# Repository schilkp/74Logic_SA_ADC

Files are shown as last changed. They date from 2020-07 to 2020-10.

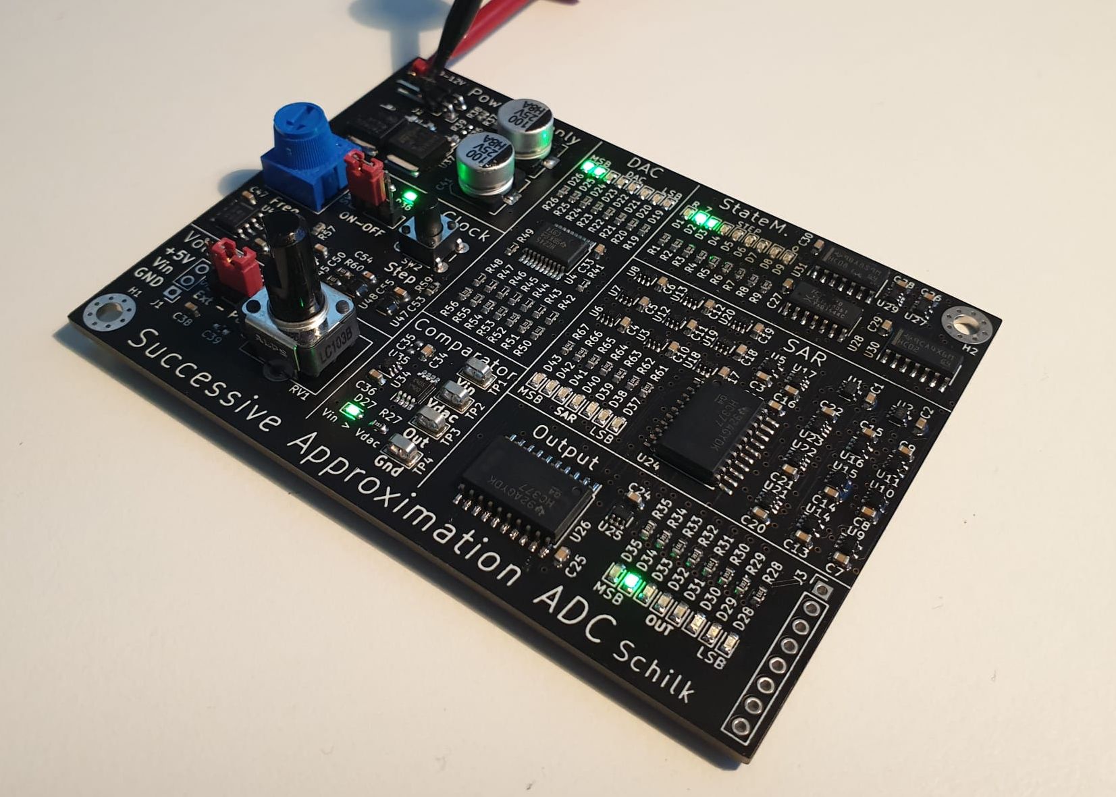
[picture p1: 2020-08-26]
Doc/SA-ADC_PCBphoto_v0.2.jpg

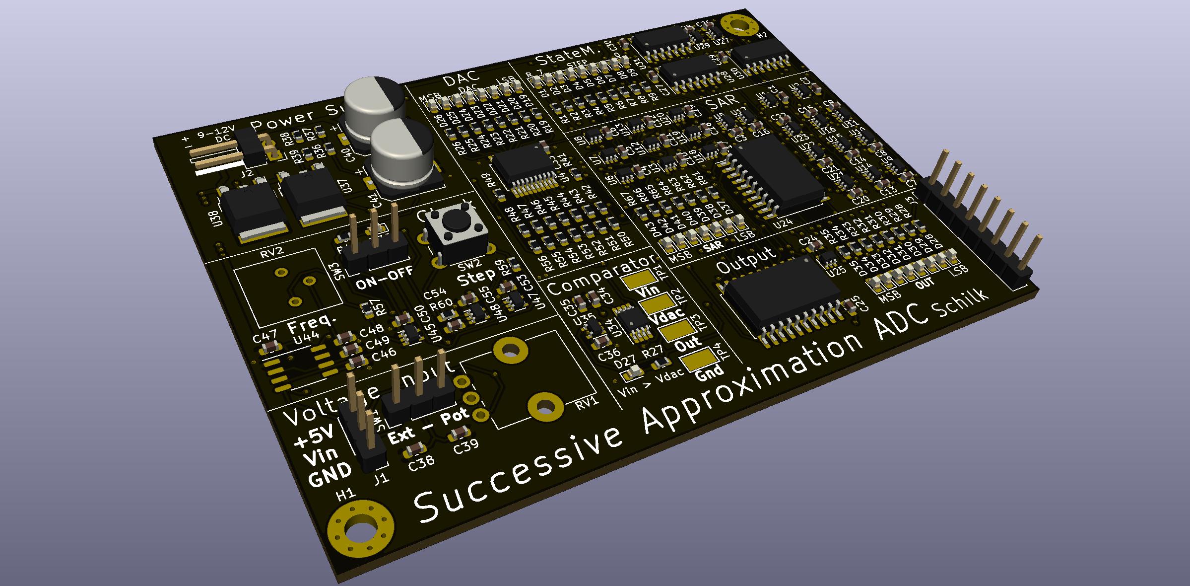
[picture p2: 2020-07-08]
Doc/SA-ADC_PCBrender_v0.2.jpg

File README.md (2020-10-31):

# SA-ADC
### Philipp Schilk
A discrete Successive-Approximation ADC built purely from 74-series gates.

Built to understand SA-ADCs, and serve as a demonstration unit.

PCB v0.2 Picture

PCB v0.2 Render

## Status
Finished. 

## Specifications
| Specification  | Value  |
| :--- | ---: |
| Resolution  | 8-bit  |
| Sample Rate  |  1Hz - 90Hz |
| Input Voltage Range | 0-5V |
| Input | Single-ended|
| Input Source | Included Potentiometer or External Input |
| Supply Voltage | 9-12Vdc |
| Output | 8-bit parallel |

As this is a demonstration unit only really meant for DC inputs, no Sample-&-Hold
stage is included.

## Successive Approximation Architecture

This Project uses the classic DAC-based Successive Approximation Architecture [Wikipedia](https://en.wikipedia.org/wiki/Successive_approximation_ADC "DAC-based Successive Approxmation Architecture").

It is essentially an analog implementation of a binary-search algorithm. The ADC first
it's DAC to 2.5V (Vref/2), and uses an analog comparator to determine if the applied input voltage is 
higher or lower than the generated voltage. Depending on the comparator's output the DAC voltage is 
then repeatedly refined to determine each bit of the conversion-result successively.

The steps of the conversion are show in the State-Machine outputs/LEDs:

|  LED  | Description |
| --- | --- |
| R | SAR (Successive Approximation Register) bits 6-1 are reset |
| 7 | Bit 7 is tested and latched if set. |
| 6 | Bit 6 is tested and latched if set. |
| ... | ... |
| 0 | Bit 0 is tested. Bit 7-1 are latched into the output from the SAR , and bit 0 is latched from the comparator |

*A note on clocks/timing:*
The state machine/shift-register is clocked on the falling edge, while the SAR (Successive Approximation Register) and the output register are 
latched on the rising edge. Due to this, all signals (including the DAC and hence the
comparator output) are setup on the falling edge of the clock by the state machine, and have until the 
rising edge of the clock to stabilize and be latched into the different registers. This reduces the complexity of the
state machine/logic somewhat.

## Repo Overview

**Doc/**  
	Documentation  

**KiCad/**  
	KiCad Project Files (Schematic and PCB).  
	Download KiCad at [kicad-pcb.org](https://kicad-pcb.org/download/).  

**KiCad/ProductionFiles/Gerber/**  
	Gerber production files.  

**KiCad/ProductionFiles/BOM/**  
	Interactive BOM  

**Logisim/**  
	Logic Simulation.  
	Download LogiSim at [cburch.com](http://www.cburch.com/logisim/).

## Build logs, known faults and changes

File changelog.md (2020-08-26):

# v0.3

- Changed to Schmitt-Trigger ICs  
- Added pull-down resistor to Clock Enable  

# v0.2

- Fixed State machine reset circuitry.
- Fixed Sate machine LEDs.
- Update chip names in schematic
- Fixed some vias in pads.

# v0.1

- Greatly simplified state machine & clocking:
	- State machine is now based on a shift register.
	- Now clocking state machine on falling clock and registers on rising edge.
		- Enables conversion in only 9 cycles.
- Moved to smaller, 2 layer PCB.
- Added mounting holes.
- Added ground test point. 
- Changed to 0603 LEDs
- Fixed missing ground on debouncing of step button.
- Slightly adjusted value of passives around clock.
	- 1M trimmer with knob is more easily available than 5M trimmer.

# v0.0

- Initial Prototype

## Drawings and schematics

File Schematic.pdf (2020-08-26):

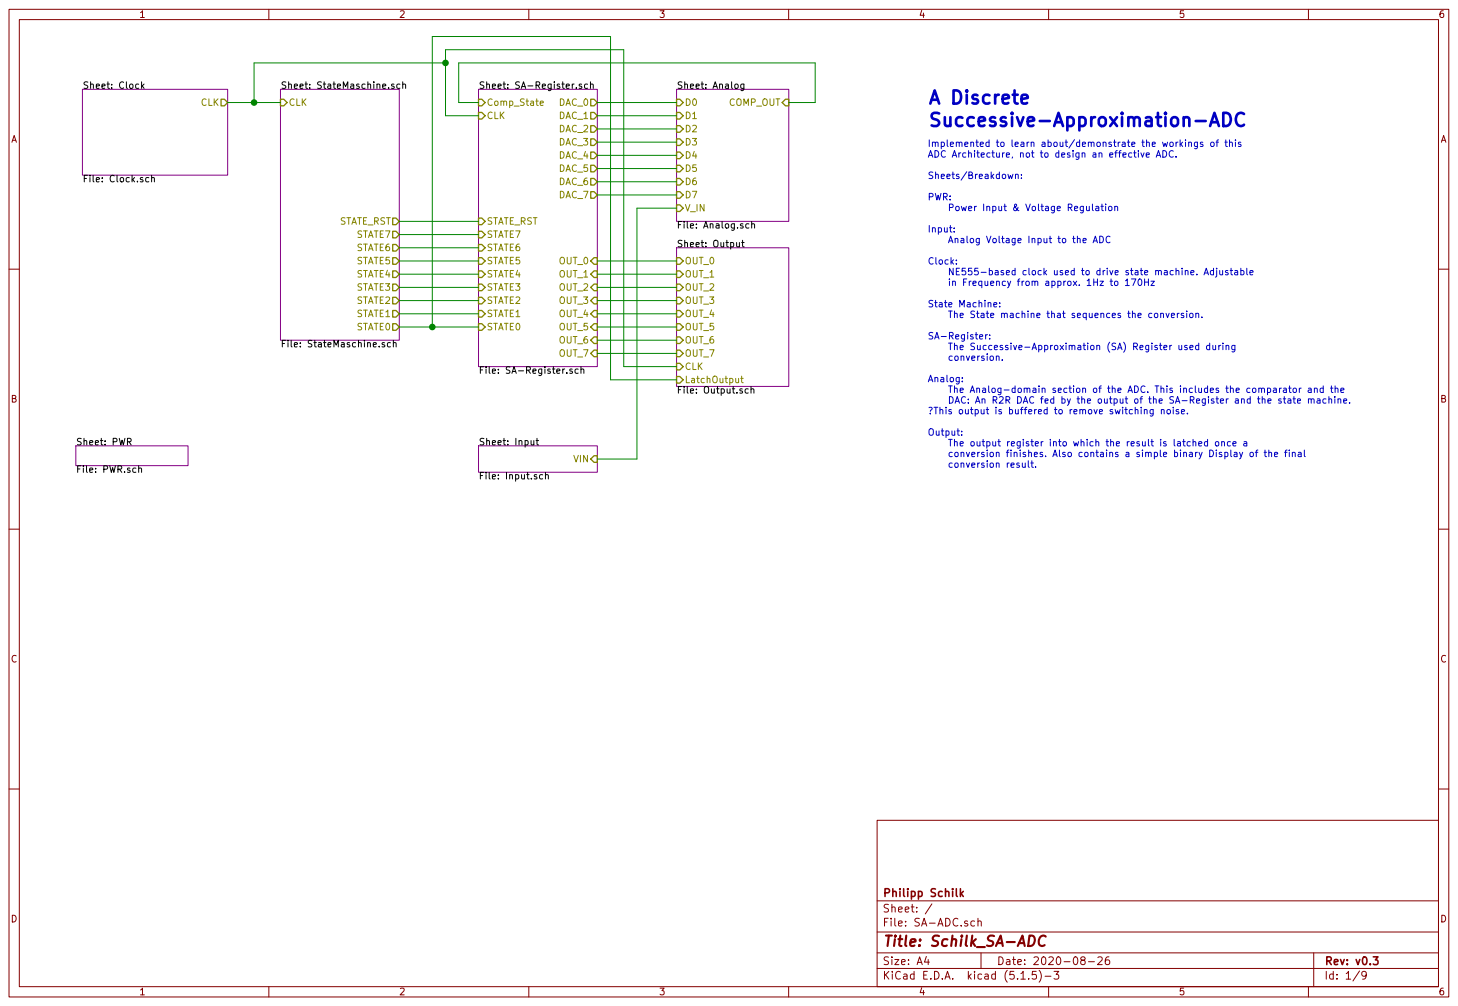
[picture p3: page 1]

COMP_OUT Sheet: StateMaschine.sch File: StateMaschine.sch CLK

Sheet: SA-Register.sch

Implemented to learn about/demonstrate the workings of this
ADC Architecture, not to design an effective ADC. Sheets/Breakdown: PWR:

Power Input & Voltage Regulation

Input:
Analog Voltage Input to the ADC

Clock:
NE555-based clock used to drive state machine. Adjustable
in Frequency from approx. 1Hz to 170Hz State Machine:

The State machine that sequences the conversion.

SA-Register:
The Successive-Approximation (SA) Register used during
conversion. Analog:

The Analog-domain section of the ADC. This includes the comparator and the
DAC: An R2R DAC fed by the output of the SA-Register and the state machine.
This output is buffered to remove switching noise.

Output:
The output register into which the result is latched once a
conversion finishes. Also contains a simple binary Display of the final

File: SA-ADC.sch Sheet: / Philipp Schilk

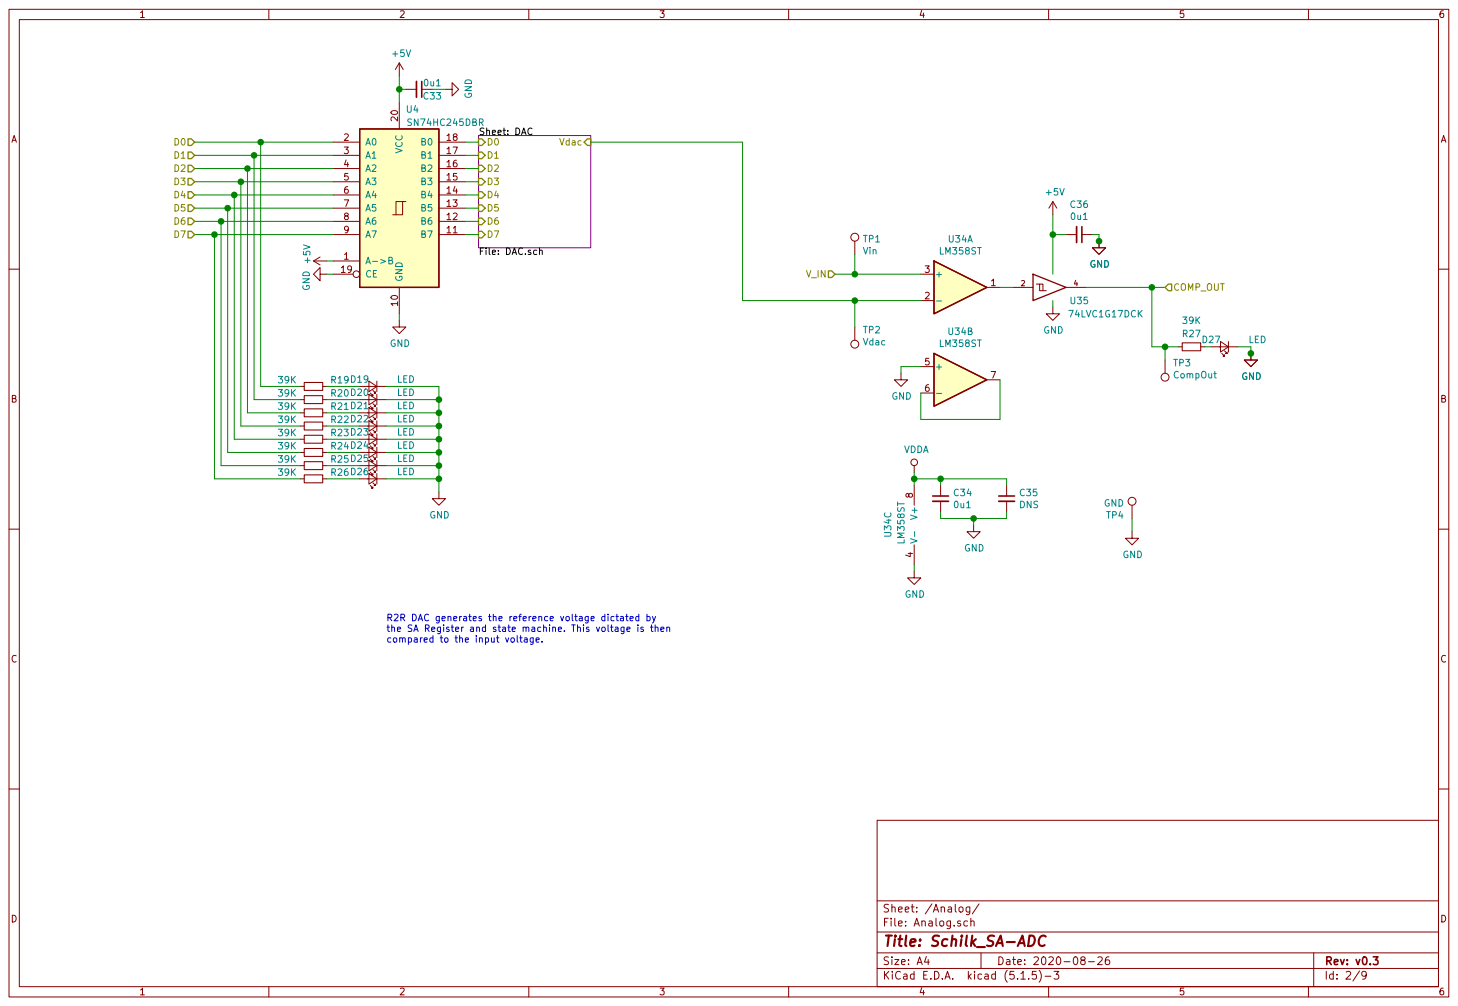
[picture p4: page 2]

the SA Register and state machine. This voltage is then
compared to the input voltage.

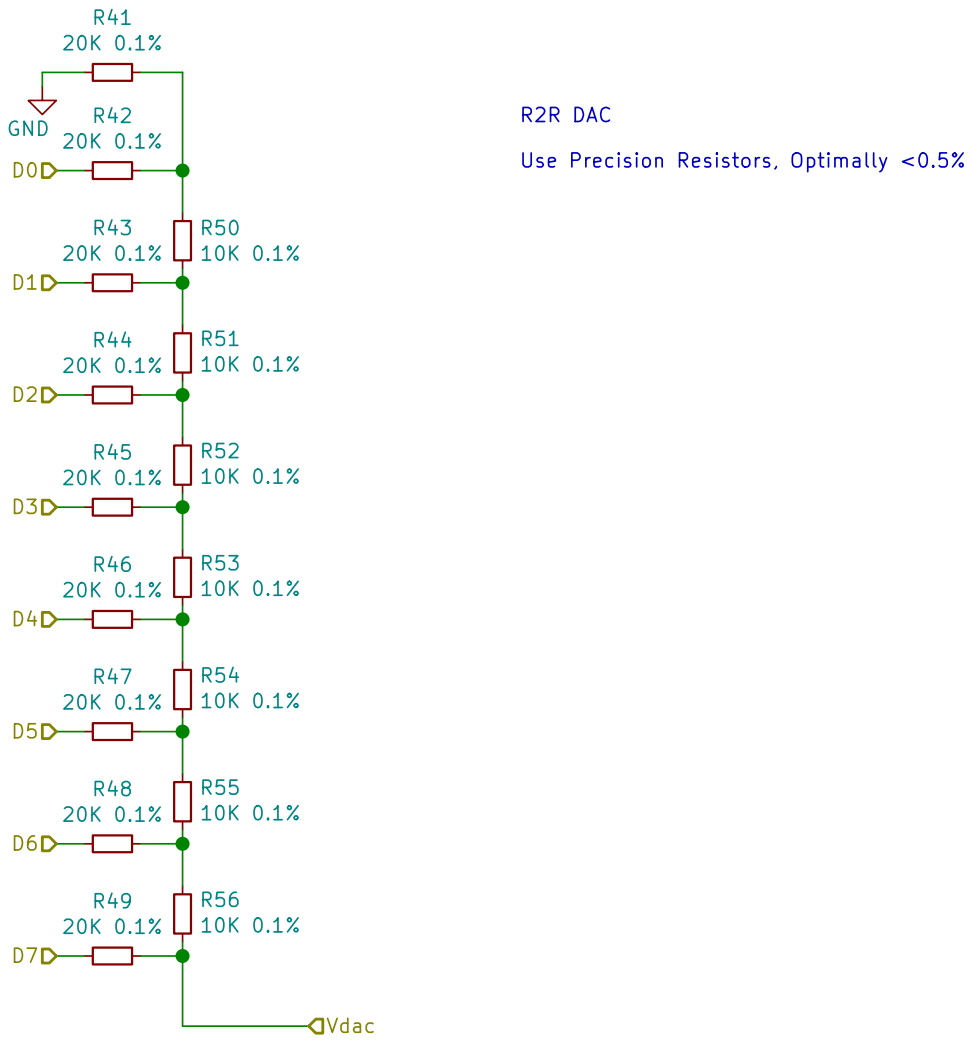
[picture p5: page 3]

Use Precision Resistors, Optimally <0.5%

File: DAC.sch Sheet: /Analog/DAC/ R56

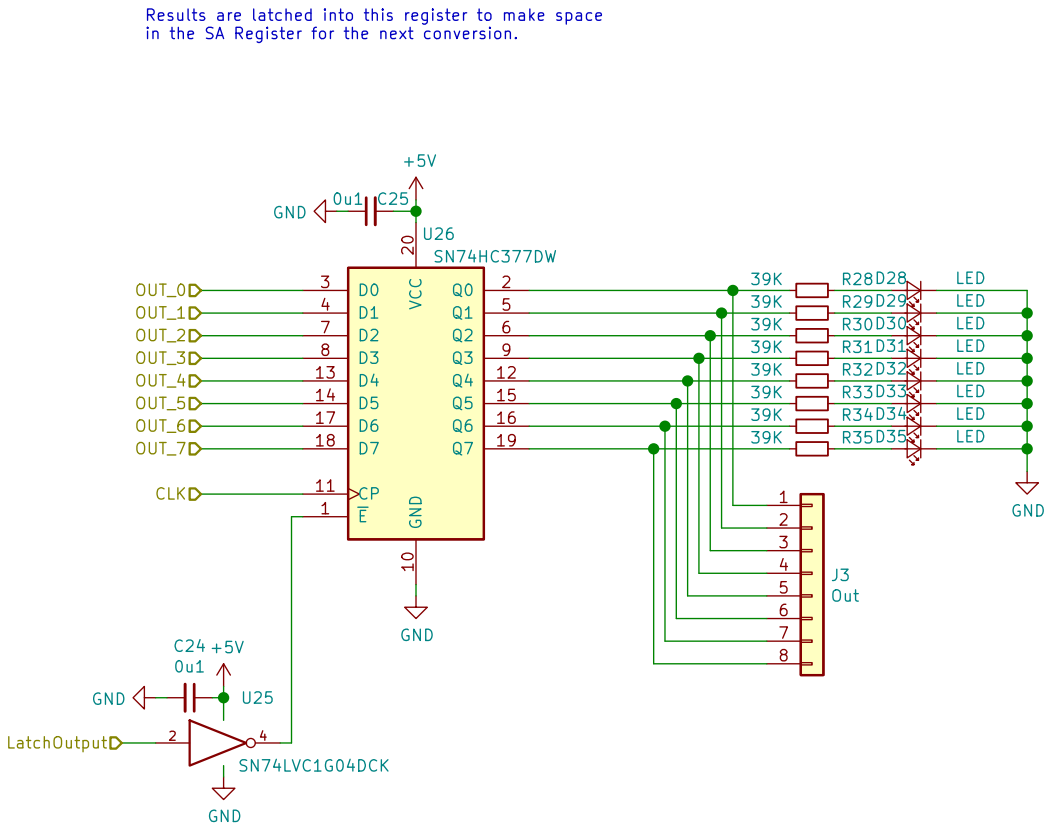
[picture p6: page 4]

in the SA Register for the next conversion.

39K R33 D33 | LED
D34 39K R34 | LED

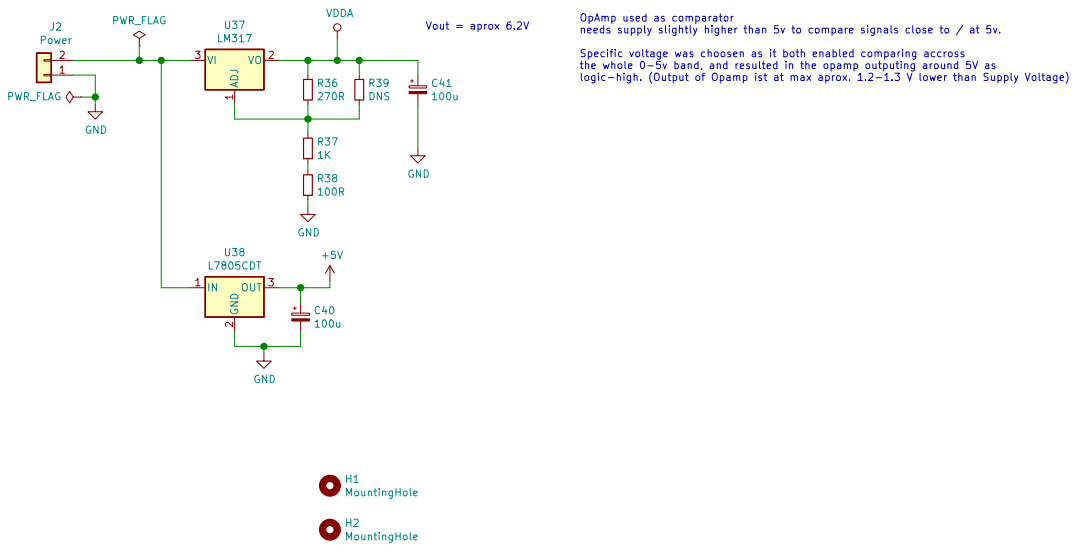
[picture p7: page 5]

needs supply slightly higher than 5v to compare signals close to / at 5v.

Specific voltage was choosen as it both enabled comparing accross
the whole 0-5v band, and resulted in the opamp outputing around 5V as
logic-high. (Output of Opamp ist at max aprox. 1.2-1.3 V lower than Supply Voltage)

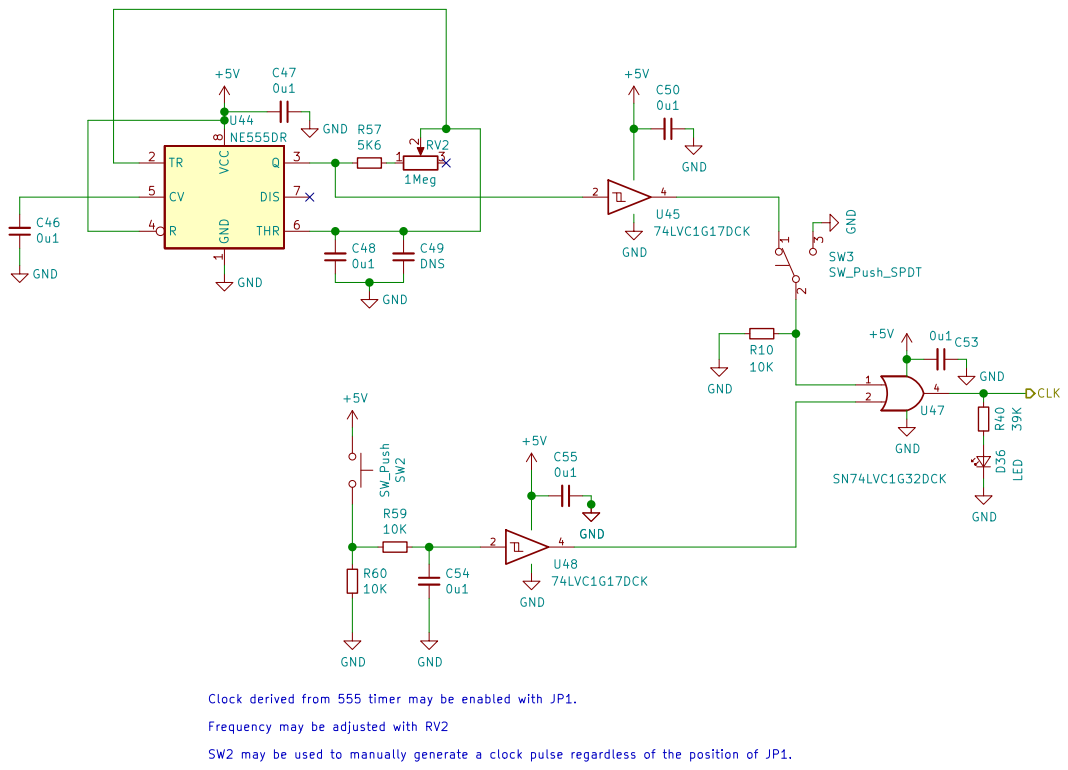
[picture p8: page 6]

File: Clock.sch Sheet: /Clock/ GND

CLK Clock derived from 555 timer may be enabled with JP1.

Frequency may be adjusted with RV2

SW2 may be used to manually generate a clock pulse regardless of the position of JP1.

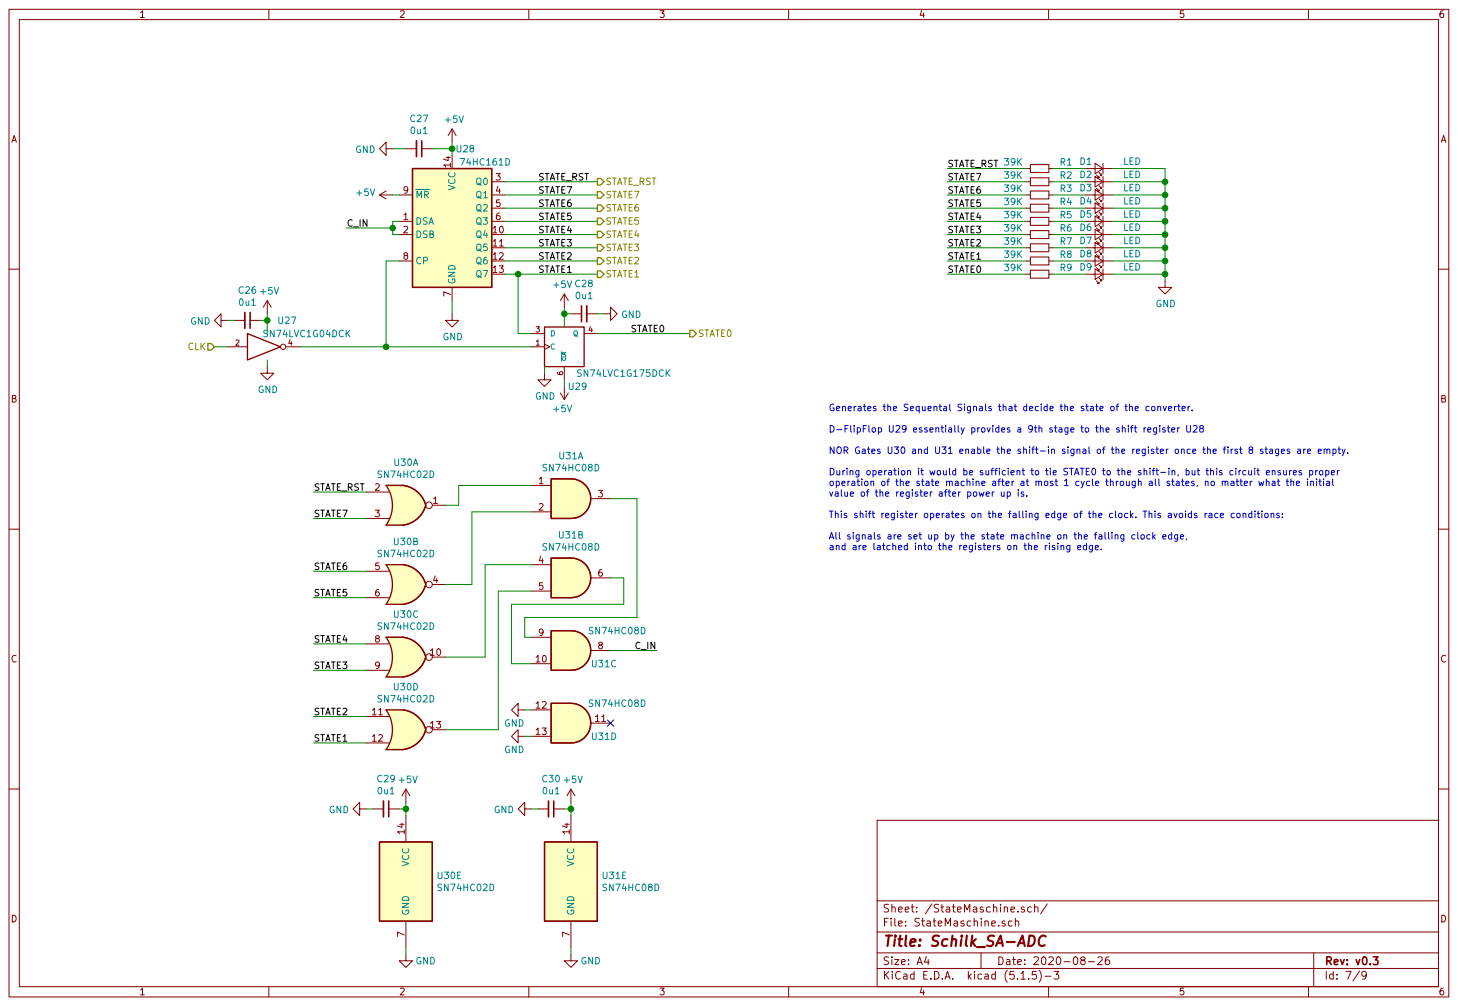
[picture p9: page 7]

D-FlipFlop U29 essentially provides a 9th stage to the shift register U28

NOR Gates U30 and U31 enable the shift-in signal of the register once the first 8 stages are empty.

During operation it would be sufficient to tie STATE0 to the shift-in, but this circuit ensures proper
operation of the state machine after at most 1 cycle through all states, no matter what the initial
value of the register after power up is.

This shift register operates on the falling edge of the clock. This avoids race conditions:

All signals are set up by the state machine on the falling clock edge,
and are latched into the registers on the rising edge.

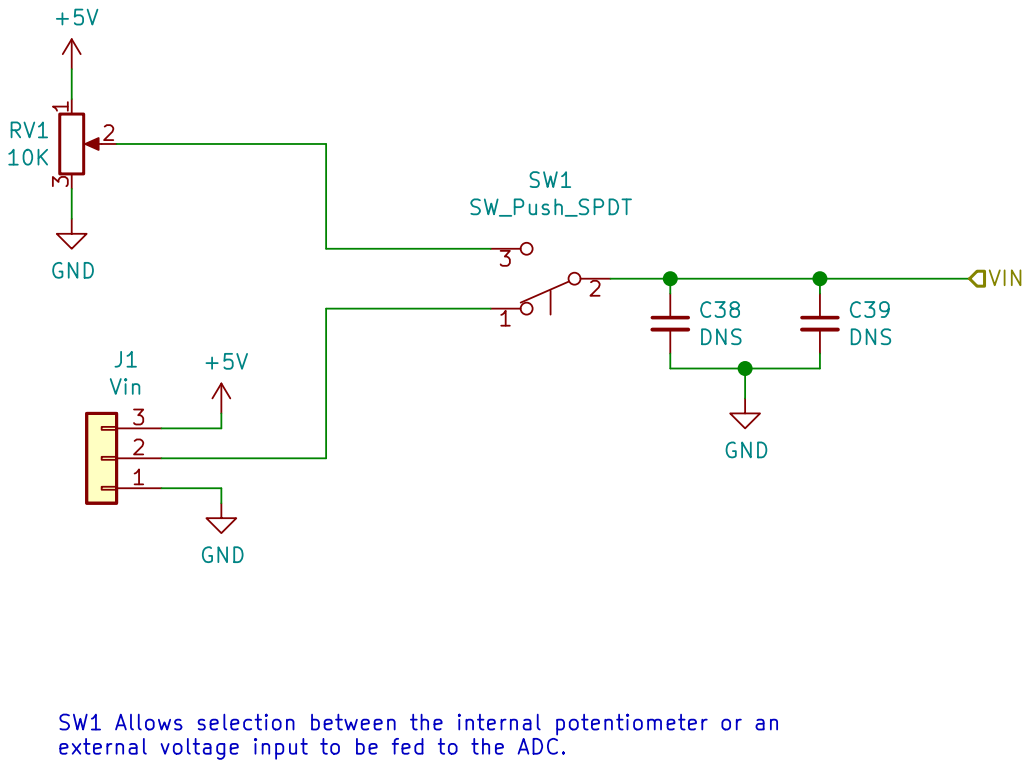
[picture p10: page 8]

SW1 Allows selection between the internal potentiometer or an
external voltage input to be fed to the ADC.

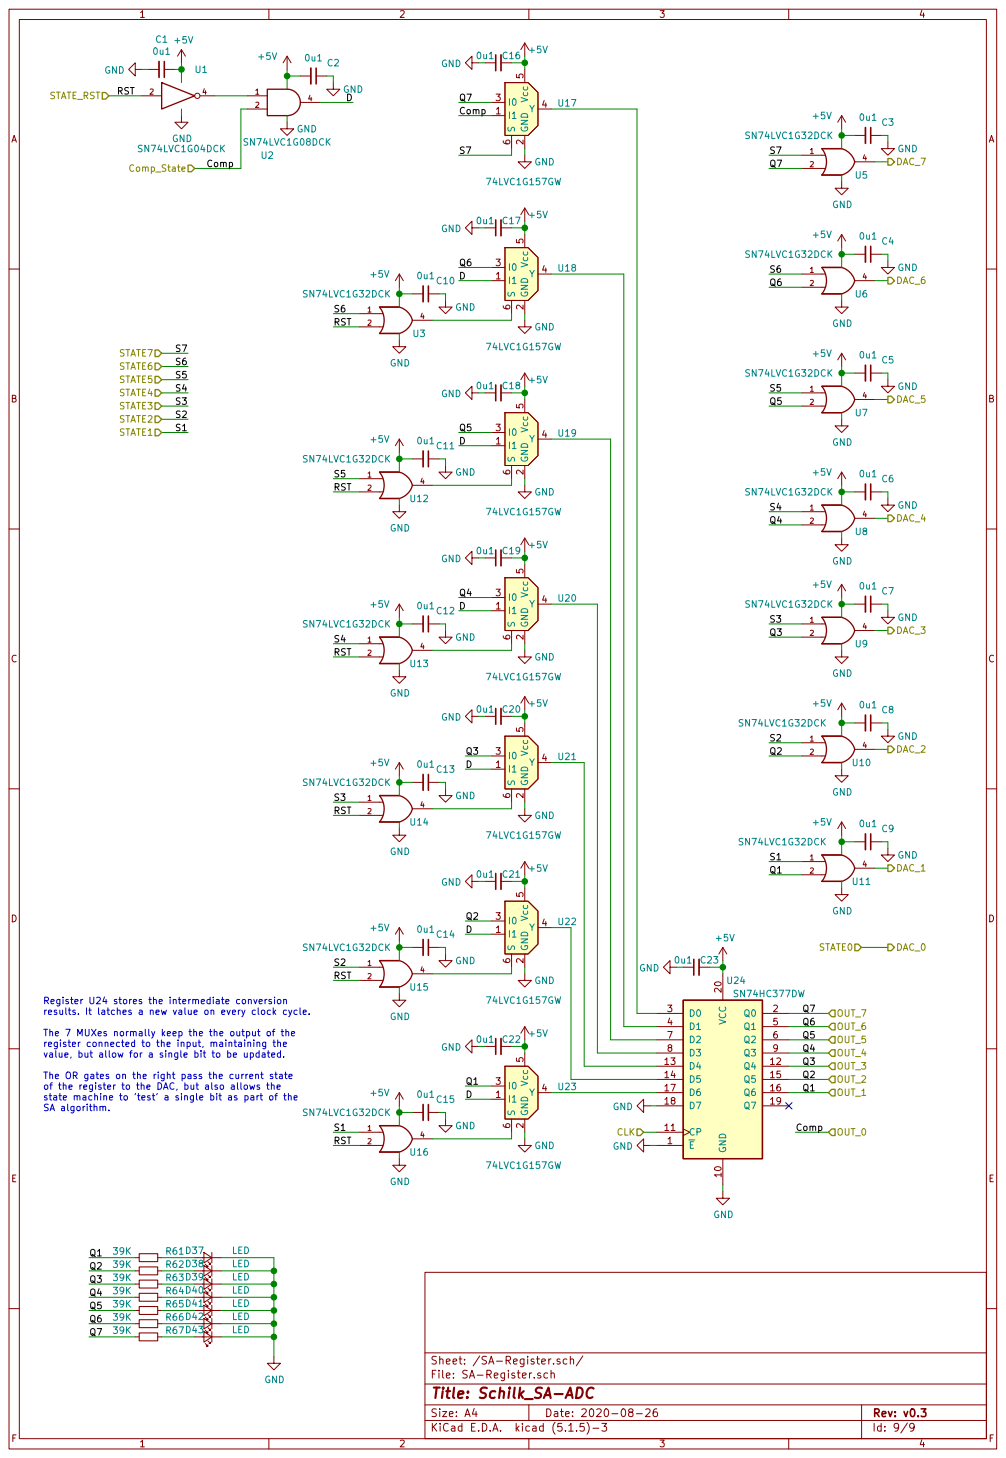
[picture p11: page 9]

results. It latches a new value on every clock cycle.

The 7 MUXes normally keep the the output of the
register connected to the input, maintaining the
value, but allow for a single bit to be updated.

The OR gates on the right pass the current state
of the register to the DAC, but also allows the
state machine to 'test' a single bit as part of the
SA algorithm.

File: SA-Register.sch
Id: 9/9 Title: Schilk_SA-ADC

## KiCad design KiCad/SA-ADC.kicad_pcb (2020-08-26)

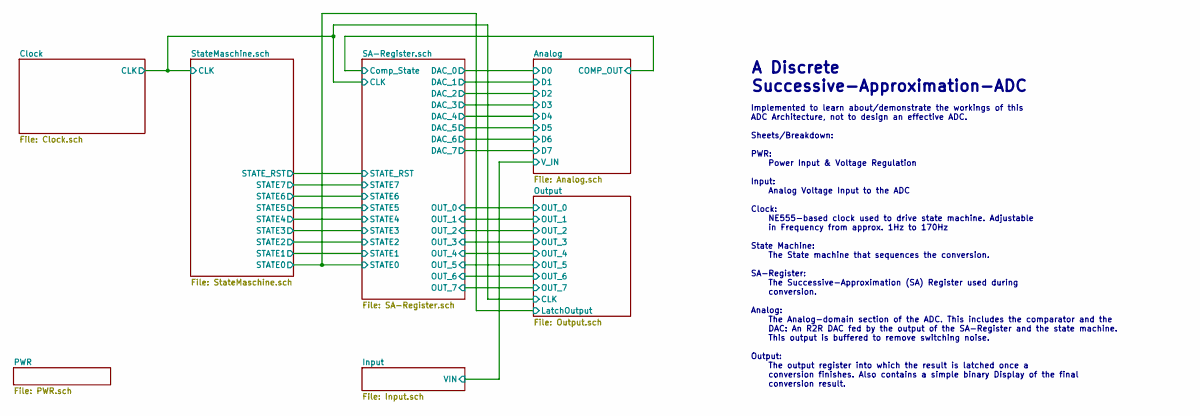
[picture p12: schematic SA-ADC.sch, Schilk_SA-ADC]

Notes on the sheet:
Implemented to learn about/demonstrate the workings of this ADC Architecture, not to design an effective ADC. Sheets/Breakdown: PWR: Power Input & Voltage Regulation Input: Analog Voltage Input to the ADC Clock: NE555-based clock used to drive state machine. Adjustable in Frequency from approx. 1Hz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
A Discrete Successive-Approximation-ADC

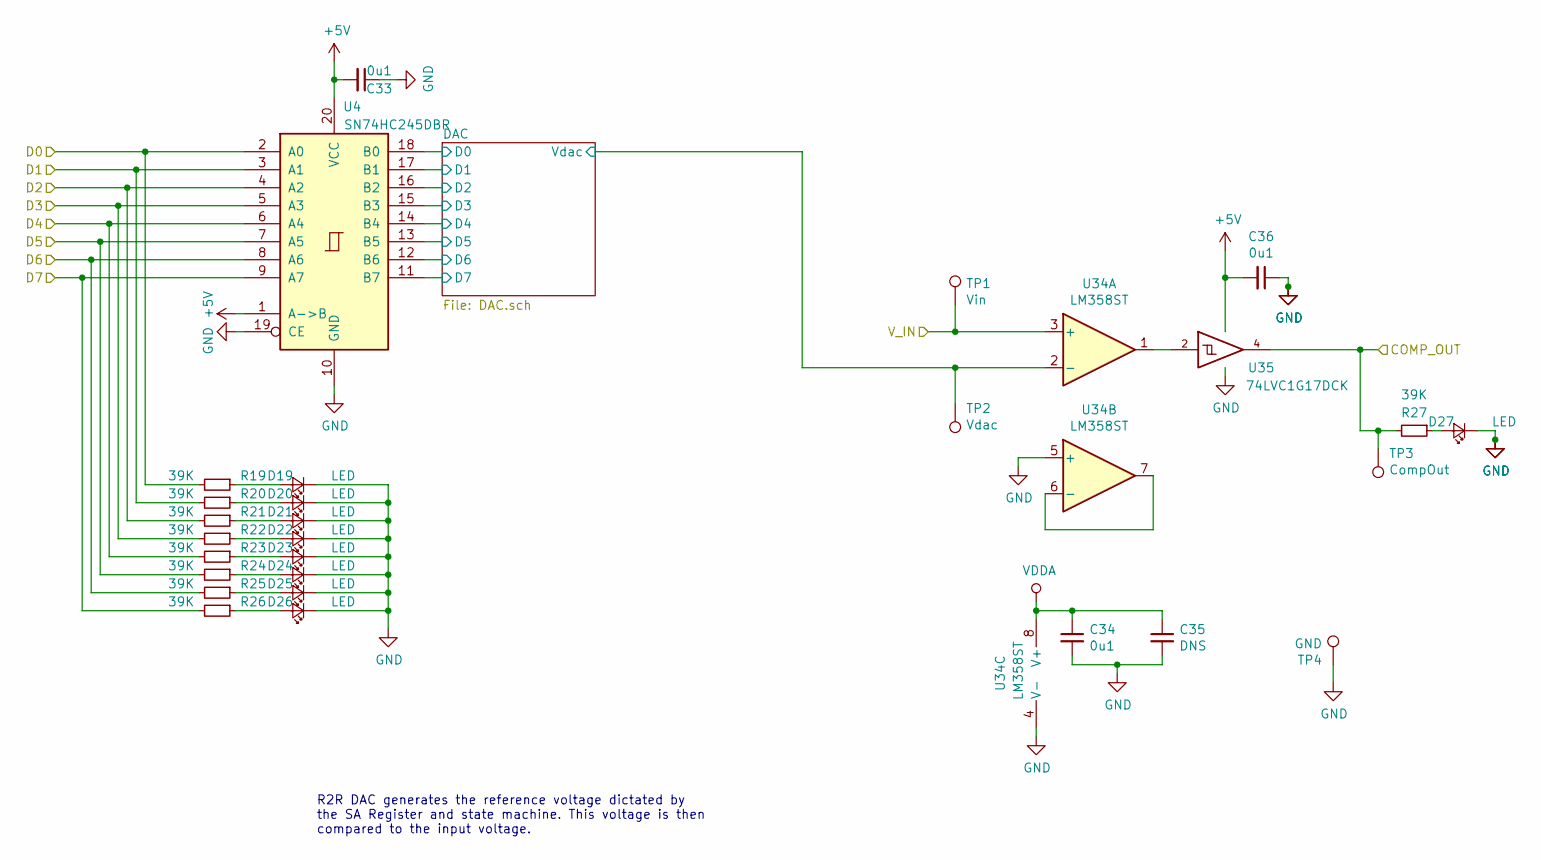
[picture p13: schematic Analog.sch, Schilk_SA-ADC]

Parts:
C33, C34, C36: 0u1; C_0603_1608Metric
C35: DNS; C_0603_1608Metric
D19, D20, D21, D22, D23, D24, D25, D26, D27: LED; LED_0603_1608Metric
R19, R20, R21, R22, R23, R24, R25, R26, R27: 39K; R_0603_1608Metric
TP1: Vin; TestPoint_Keystone_5019_Minature
TP2: Vdac; TestPoint_Keystone_5019_Minature
TP3: CompOut; TestPoint_Keystone_5019_Minature
TP4: GND; TestPoint_Keystone_5019_Minature
U4: SN74HC245DBR; SSOP-20_5.3x7.2mm_P0.65mm
U34: LM358ST; MSOP-8_3x3mm_P0.65mm
U35: 74LVC1G17DCK; SOT-353_SC-70-5

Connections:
+5V: C33.2, C36.2, U4.1 (A->B), U4.20 (VCC), U35.5 (VCC); also elsewhere on the board
/Analog/COMP_OUT: R27.2, TP3.1, U35.4; also elsewhere on the board
/Analog/D0: R19.2, U4.2 (A0); also elsewhere on the board
/Analog/D1: R20.2, U4.3 (A1); also elsewhere on the board
/Analog/D2: R21.2, U4.4 (A2); also elsewhere on the board
/Analog/D3: R22.2, U4.5 (A3); also elsewhere on the board
/Analog/D4: R23.2, U4.6 (A4); also elsewhere on the board
/Analog/D5: R24.2, U4.7 (A5); also elsewhere on the board
/Analog/D6: R25.2, U4.8 (A6); also elsewhere on the board
/Analog/D7: R26.2, U4.9 (A7); also elsewhere on the board
/Analog/DAC/D0: U4.18 (B0); also elsewhere on the board
/Analog/DAC/D1: U4.17 (B1); also elsewhere on the board
/Analog/DAC/D2: U4.16 (B2); also elsewhere on the board
/Analog/DAC/D3: U4.15 (B3); also elsewhere on the board
/Analog/DAC/D4: U4.14 (B4); also elsewhere on the board
/Analog/DAC/D5: U4.13 (B5); also elsewhere on the board
/Analog/DAC/D6: U4.12 (B6); also elsewhere on the board
/Analog/DAC/D7: U4.11 (B7); also elsewhere on the board
/Analog/DAC/Vdac: TP2.1, U34.2 (-); also elsewhere on the board
/Input/VIN: TP1.1, U34.3 (+); also elsewhere on the board
GND: C33.1, C34.2, C35.2, C36.1, D19.1 (K), D20.1 (K), D21.1 (K), D22.1 (K), D23.1 (K), D24.1 (K), D25.1 (K), D26.1 (K), D27.1 (K), TP4.1, U4.10 (GND), U4.19 (CE), U34.4 (V-), U34.5 (+), U35.3 (GND); also elsewhere on the board
unnamed: D19.2 (A), R19.1
unnamed: D20.2 (A), R20.1
unnamed: D21.2 (A), R21.1
unnamed: D22.2 (A), R22.1
unnamed: D23.2 (A), R23.1
unnamed: D24.2 (A), R24.1
unnamed: D25.2 (A), R25.1
unnamed: D26.2 (A), R26.1
unnamed: D27.2 (A), R27.1
unnamed: U34.1, U35.2
unnamed: U34.6 (-), U34.7
VDDA: C34.1, C35.1, U34.8 (V+); also elsewhere on the board

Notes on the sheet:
R2R DAC generates the reference voltage dictated by the SA Register and state machine. This voltage is then compared to the input voltage.

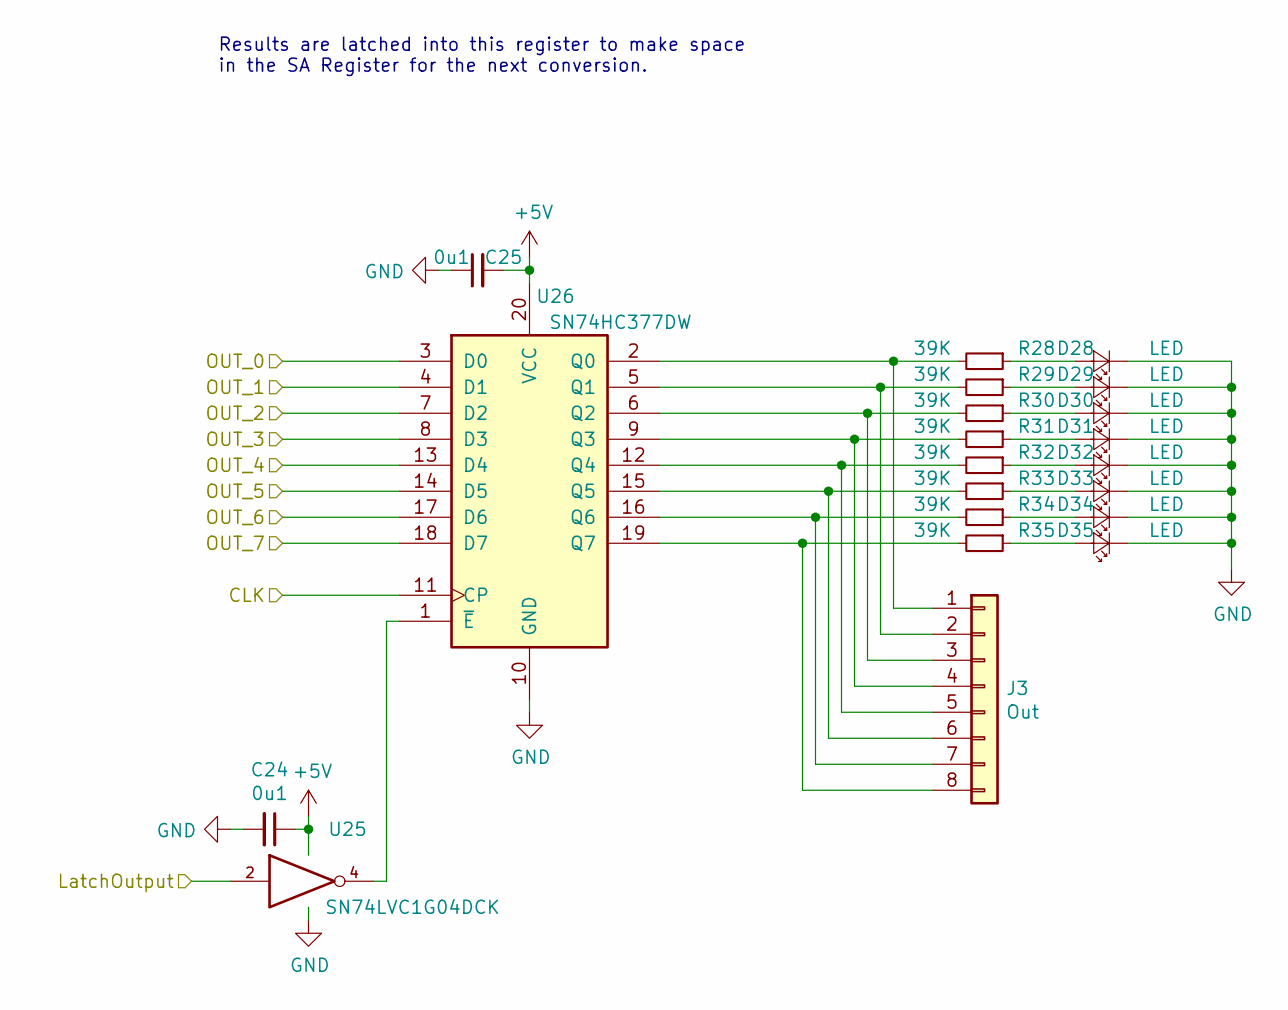
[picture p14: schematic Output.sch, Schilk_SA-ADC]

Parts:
C24, C25: 0u1; C_0603_1608Metric
D28, D29, D30, D31, D32, D33, D34, D35: LED; LED_0603_1608Metric
J3: Out; PinHeader_1x08_P2.54mm_Vertical
R28, R29, R30, R31, R32, R33, R34, R35: 39K; R_0603_1608Metric
U25: SN74LVC1G04DCK; SOT-353_SC-70-5
U26: SN74HC377DW; SOIC-20W_7.5x12.8mm_P1.27mm

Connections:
+5V: C24.1, C25.2, U25.5 (VCC), U26.20 (VCC); also elsewhere on the board
/Analog/COMP_OUT: U26.3 (D0); also elsewhere on the board
/Analog/D0: U25.2; also elsewhere on the board
/Clock/CLK: U26.11 (CP); also elsewhere on the board
/Output/OUT_1: U26.4 (D1); also elsewhere on the board
/Output/OUT_2: U26.7 (D2); also elsewhere on the board
/Output/OUT_3: U26.8 (D3); also elsewhere on the board
/Output/OUT_4: U26.13 (D4); also elsewhere on the board
/Output/OUT_5: U26.14 (D5); also elsewhere on the board
/Output/OUT_6: U26.17 (D6); also elsewhere on the board
/Output/OUT_7: U26.18 (D7); also elsewhere on the board
GND: C24.2, C25.1, D28.1 (K), D29.1 (K), D30.1 (K), D31.1 (K), D32.1 (K), D33.1 (K), D34.1 (K), D35.1 (K), U25.3 (GND), U26.10 (GND); also elsewhere on the board
unnamed: D28.2 (A), R28.1
unnamed: D29.2 (A), R29.1
unnamed: D30.2 (A), R30.1
unnamed: D31.2 (A), R31.1
unnamed: D32.2 (A), R32.1
unnamed: D33.2 (A), R33.1
unnamed: D34.2 (A), R34.1
unnamed: D35.2 (A), R35.1
unnamed: J3.1, R28.2, U26.2 (Q0)
unnamed: J3.2, R29.2, U26.5 (Q1)
unnamed: J3.3, R30.2, U26.6 (Q2)
unnamed: J3.4, R31.2, U26.9 (Q3)
unnamed: J3.5, R32.2, U26.12 (Q4)
unnamed: J3.6, R33.2, U26.15 (Q5)
unnamed: J3.7, R34.2, U26.16 (Q6)
unnamed: J3.8, R35.2, U26.19 (Q7)
unnamed: U25.4, U26.1 (~E)

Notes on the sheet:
Results are latched into this register to make space in the SA Register for the next conversion.

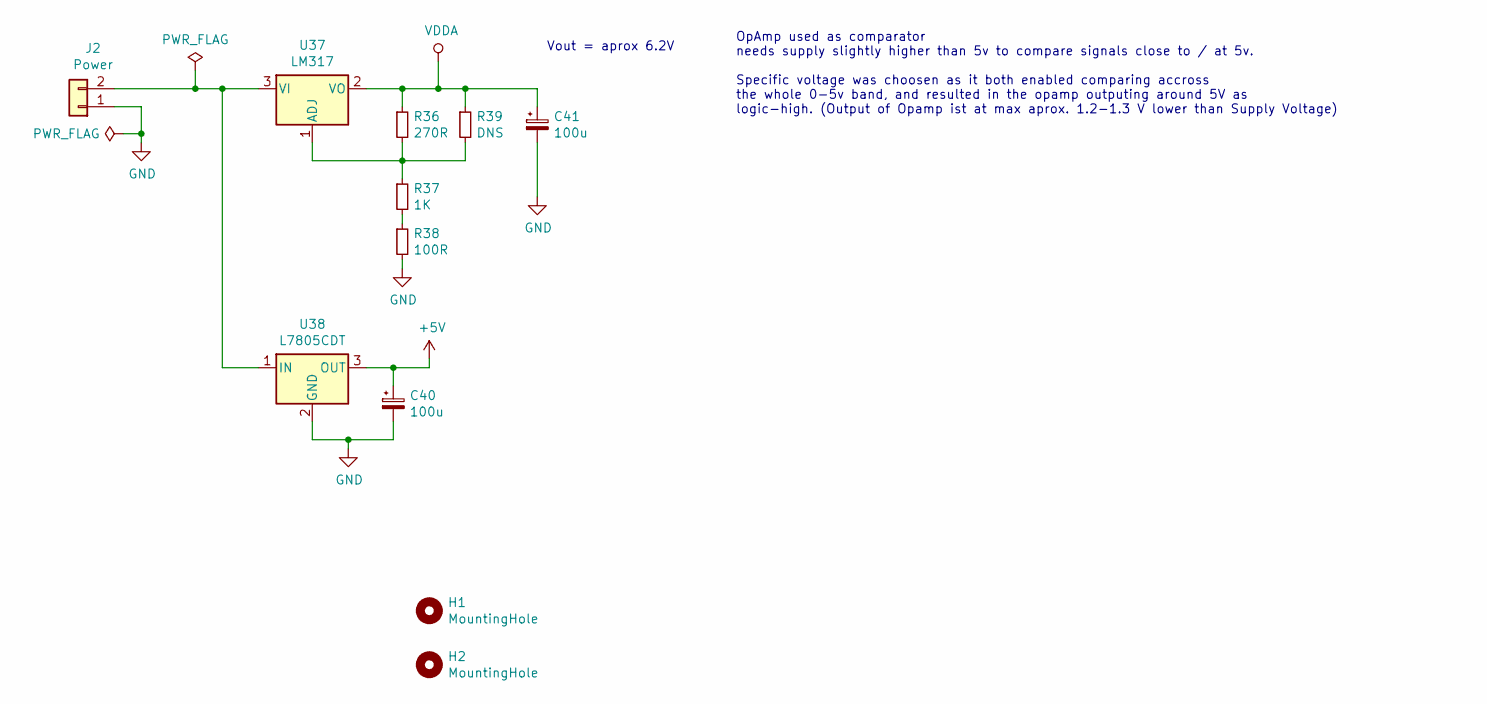
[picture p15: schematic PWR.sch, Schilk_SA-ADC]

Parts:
C40, C41: 100u; CP_Elec_8x6.5
H1, H2: MountingHole; MountingHole_3.2mm_M3_Pad_Via
J2: Power; PinHeader_1x02_P2.54mm_Horizontal
R36: 270R; R_0603_1608Metric
R37: 1K; R_0603_1608Metric
R38: 100R; R_0603_1608Metric
R39: DNS; R_0603_1608Metric
U37: LM317; TO-252-2
U38: L7805CDT; TO-252-2

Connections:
+5V: C40.1, U38.3 (OUT); also elsewhere on the board
GND: C40.2, C41.2, J2.1, R38.2, U38.2 (GND); also elsewhere on the board
unnamed: J2.2, U37.3 (VI), U38.1 (IN)
unnamed: R36.2, R37.1, R39.2, U37.1 (ADJ)
unnamed: R37.2, R38.1
VDDA: C41.1, R36.1, R39.1, U37.2 (VO); also elsewhere on the board

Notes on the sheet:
Vout = aprox 6.2V
OpAmp used as comparator needs supply slightly higher than 5v to compare signals close to / at 5v. Specific voltage was choosen as it both enabled comparing accross the whole 0-5v band, and resulted in the opamp outputing around 5V as logic-high. (Output of Opamp ist at max aprox. 1.2-1.3 V lower t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

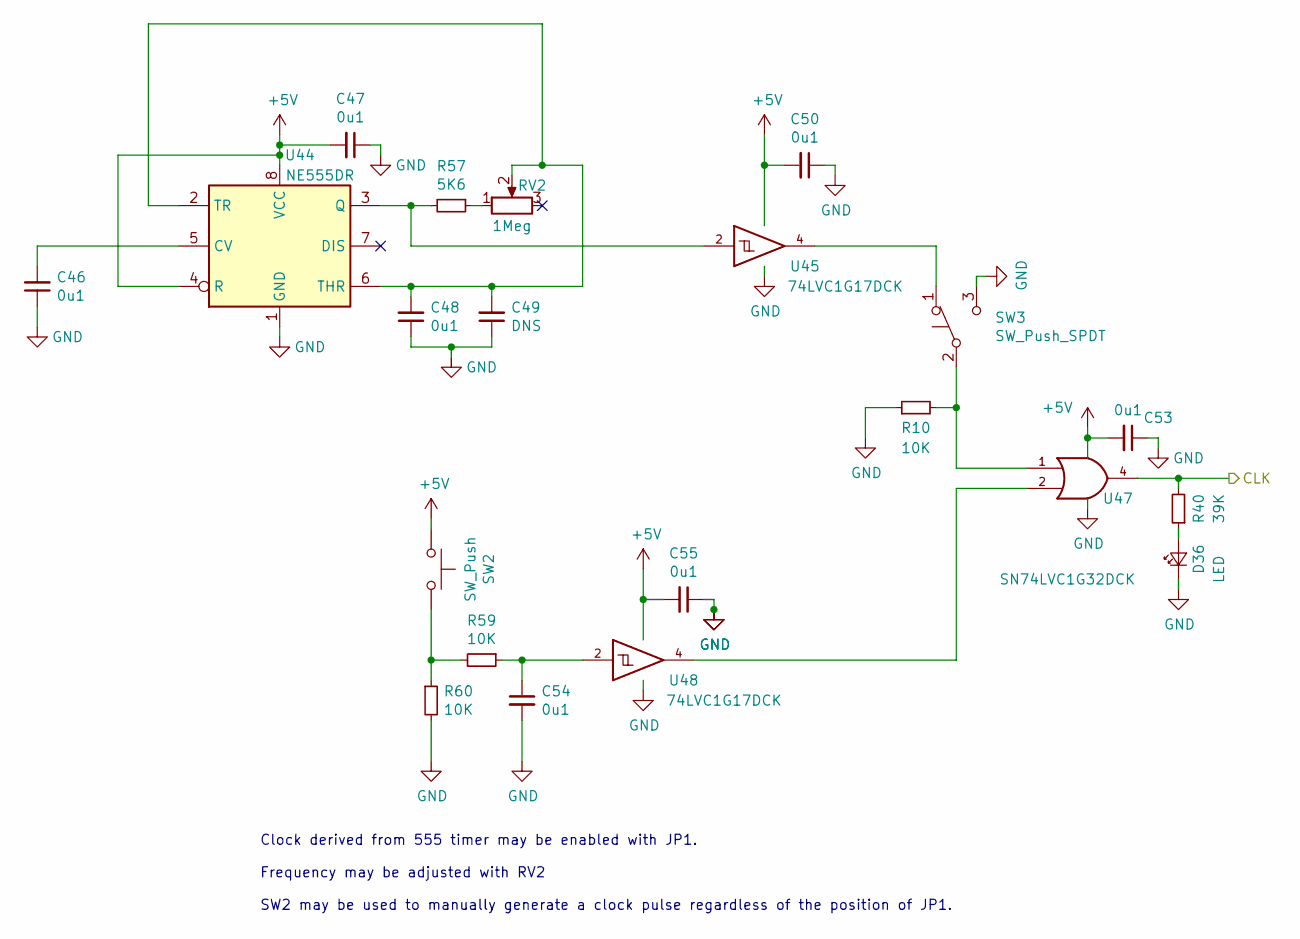
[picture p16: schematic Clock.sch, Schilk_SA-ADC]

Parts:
C46, C47, C48, C50, C53, C54, C55: 0u1; C_0603_1608Metric
C49: DNS; C_0603_1608Metric
D36: LED; LED_0603_1608Metric
R10, R59, R60: 10K; R_0603_1608Metric
R40: 39K; R_0603_1608Metric
R57: 5K6; R_0603_1608Metric
RV2: 1Meg; Potentiometer_Bourns_3386P_Vertical
SW2: SW_Push; SW_PUSH_6mm
SW3: SW_Push_SPDT; PinHeader_1x03_P2.54mm_Vertical
U44: NE555DR; SOP-8_3.9x4.9mm_P1.27mm
U45, U48: 74LVC1G17DCK; SOT-353_SC-70-5
U47: SN74LVC1G32DCK; SOT-353_SC-70-5

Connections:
+5V: C47.2, C50.2, C53.2, C55.2, SW2.1, U44.4 (R), U44.8 (VCC), U45.5 (VCC), U47.5 (VCC), U48.5 (VCC); also elsewhere on the board
/Clock/CLK: R40.2, U47.4; also elsewhere on the board
GND: C46.1, C47.1, C48.1, C49.1, C50.1, C53.1, C54.2, C55.1, D36.1 (K), R10.1, R60.2, SW3.3 (C), U44.1 (GND), U45.3 (GND), U47.3 (GND), U48.3 (GND); also elsewhere on the board
unnamed: C46.2, U44.5 (CV)
unnamed: C48.2, C49.2, RV2.2, U44.2 (TR), U44.6 (THR)
unnamed: C54.1, R59.1, U48.2
unnamed: D36.2 (A), R40.1
unnamed: R10.2, SW3.2 (B), U47.1
unnamed: R57.1, RV2.1
unnamed: R57.2, U44.3 (Q), U45.2
unnamed: R59.2, R60.1, SW2.2
unnamed: SW3.1 (A), U45.4
unnamed: U47.2, U48.4

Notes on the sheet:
Clock derived from 555 timer may be enabled with JP1. Frequency may be adjusted with RV2 SW2 may be used to manually generate a clock pulse regardless of the position of JP1.

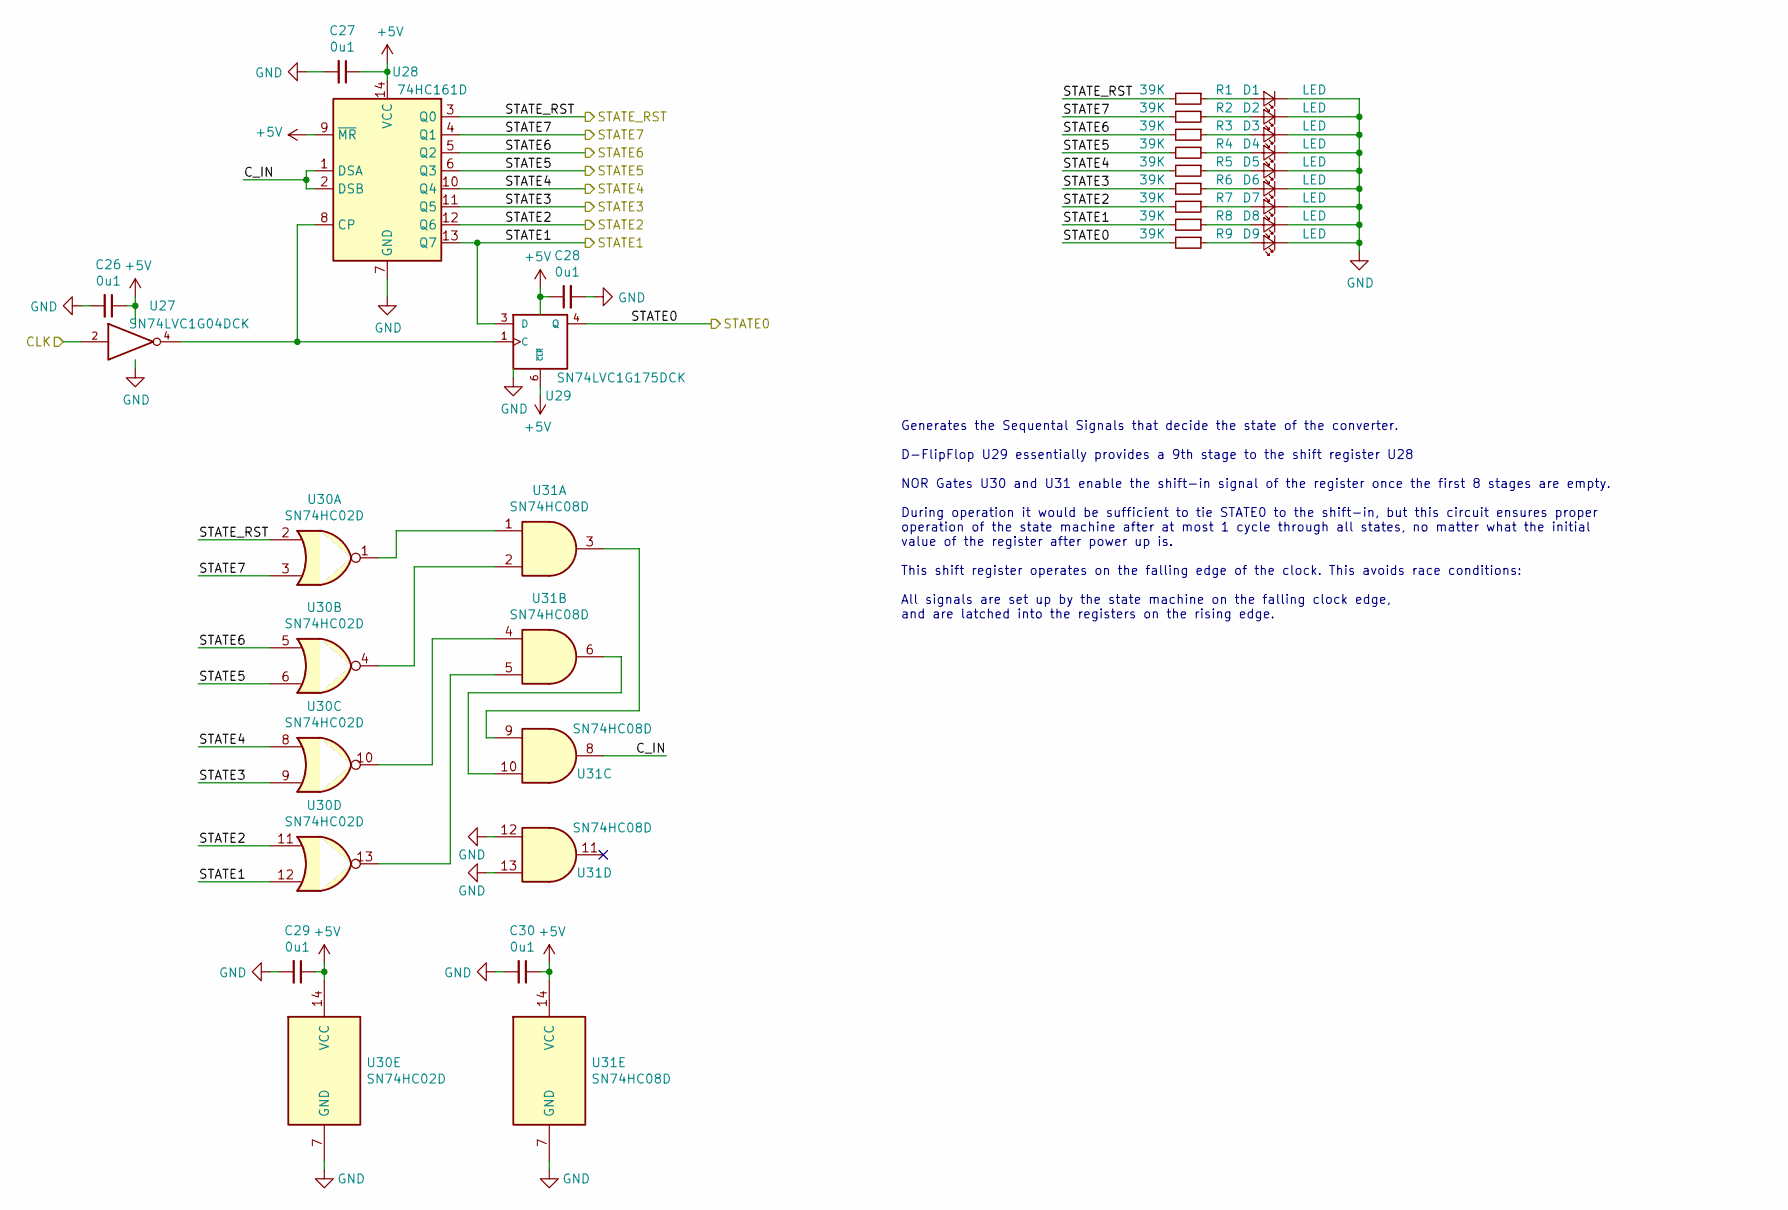
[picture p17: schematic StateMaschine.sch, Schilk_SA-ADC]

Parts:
C26, C27, C28, C29, C30: 0u1; C_0603_1608Metric
D1, D2, D3, D4, D5, D6, D7, D8, D9: LED; LED_0603_1608Metric
R1, R2, R3, R4, R5, R6, R7, R8, R9: 39K; R_0603_1608Metric
U27: SN74LVC1G04DCK; SOT-353_SC-70-5
U28: 74HC161D; SOIC-14_3.9x8.7mm_P1.27mm
U29: SN74LVC1G175DCK; SOT-363_SC-70-6
U30: SN74HC02D; SOIC-14_3.9x8.7mm_P1.27mm
U31: SN74HC08D; SOIC-14_3.9x8.7mm_P1.27mm

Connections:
+5V: C26.1, C27.1, C28.1, C29.1, C30.1, U27.5 (VCC), U28.9 (~MR), U28.14 (VCC), U29.5 (VCC), U29.6 (~CLR), U30.14 (VCC), U31.14 (VCC); also elsewhere on the board
/Analog/D0: R9.2, U29.4 (Q); also elsewhere on the board
/Clock/CLK: U27.2; also elsewhere on the board
/SA-Register.sch/STATE1: R8.2, U28.13 (Q7), U29.3 (D), U30.12; also elsewhere on the board
/SA-Register.sch/STATE2: R7.2, U28.12 (Q6), U30.11; also elsewhere on the board
/SA-Register.sch/STATE3: R6.2, U28.11 (Q5), U30.9; also elsewhere on the board
/SA-Register.sch/STATE4: R5.2, U28.10 (Q4), U30.8; also elsewhere on the board
/SA-Register.sch/STATE5: R4.2, U28.6 (Q3), U30.6; also elsewhere on the board
/SA-Register.sch/STATE6: R3.2, U28.5 (Q2), U30.5; also elsewhere on the board
/SA-Register.sch/STATE7: R2.2, U28.4 (Q1), U30.3; also elsewhere on the board
/SA-Register.sch/STATE_RST: R1.2, U28.3 (Q0), U30.2; also elsewhere on the board
/StateMaschine.sch/C_IN: U28.1 (DSA), U28.2 (DSB), U31.8
GND: C26.2, C27.2, C28.2, C29.2, C30.2, D1.1 (K), D2.1 (K), D3.1 (K), D4.1 (K), D5.1 (K), D6.1 (K), D7.1 (K), D8.1 (K), D9.1 (K), U27.3 (GND), U28.7 (GND), U29.2 (GND), U30.7 (GND), U31.7 (GND), U31.12, U31.13; also elsewhere on the board
unnamed: D1.2 (A), R1.1
unnamed: D2.2 (A), R2.1
unnamed: D3.2 (A), R3.1
unnamed: D4.2 (A), R4.1
unnamed: D5.2 (A), R5.1
unnamed: D6.2 (A), R6.1
unnamed: D7.2 (A), R7.1
unnamed: D8.2 (A), R8.1
unnamed: D9.2 (A), R9.1
unnamed: U27.4, U28.8 (CP), U29.1 (C)
unnamed: U30.1, U31.1
unnamed: U30.4, U31.2
unnamed: U30.10, U31.4
unnamed: U30.13, U31.5
unnamed: U31.3, U31.9
unnamed: U31.6, U31.10

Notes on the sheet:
Generates the Sequental Signals that decide the state of the converter. D-FlipFlop U29 essentially provides a 9th stage to the shift register U28 NOR Gates U30 and U31 enable the shift-in signal of the register once the first 8 stages are empty. During operation it would be sufficient to tie STATE0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

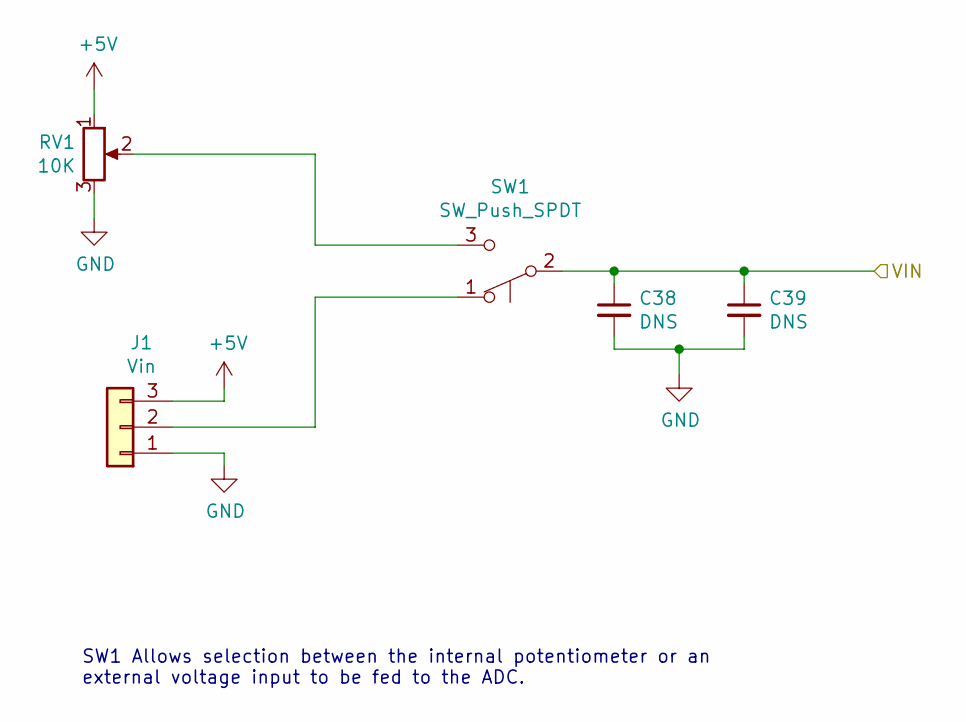
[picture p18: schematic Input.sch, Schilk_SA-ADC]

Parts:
C38, C39: DNS; C_0603_1608Metric
J1: Vin; PinHeader_1x03_P2.54mm_Vertical
RV1: 10K; Potentiometer_Alps_RK09K_Single_Vertical
SW1: SW_Push_SPDT; PinHeader_1x03_P2.54mm_Vertical

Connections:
+5V: J1.3, RV1.1; also elsewhere on the board
/Input/VIN: C38.1, C39.1, SW1.2 (B); also elsewhere on the board
GND: C38.2, C39.2, J1.1, RV1.3; also elsewhere on the board
unnamed: J1.2, SW1.1 (A)
unnamed: RV1.2, SW1.3 (C)

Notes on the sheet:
SW1 Allows selection between the internal potentiometer or an external voltage input to be fed to the ADC.

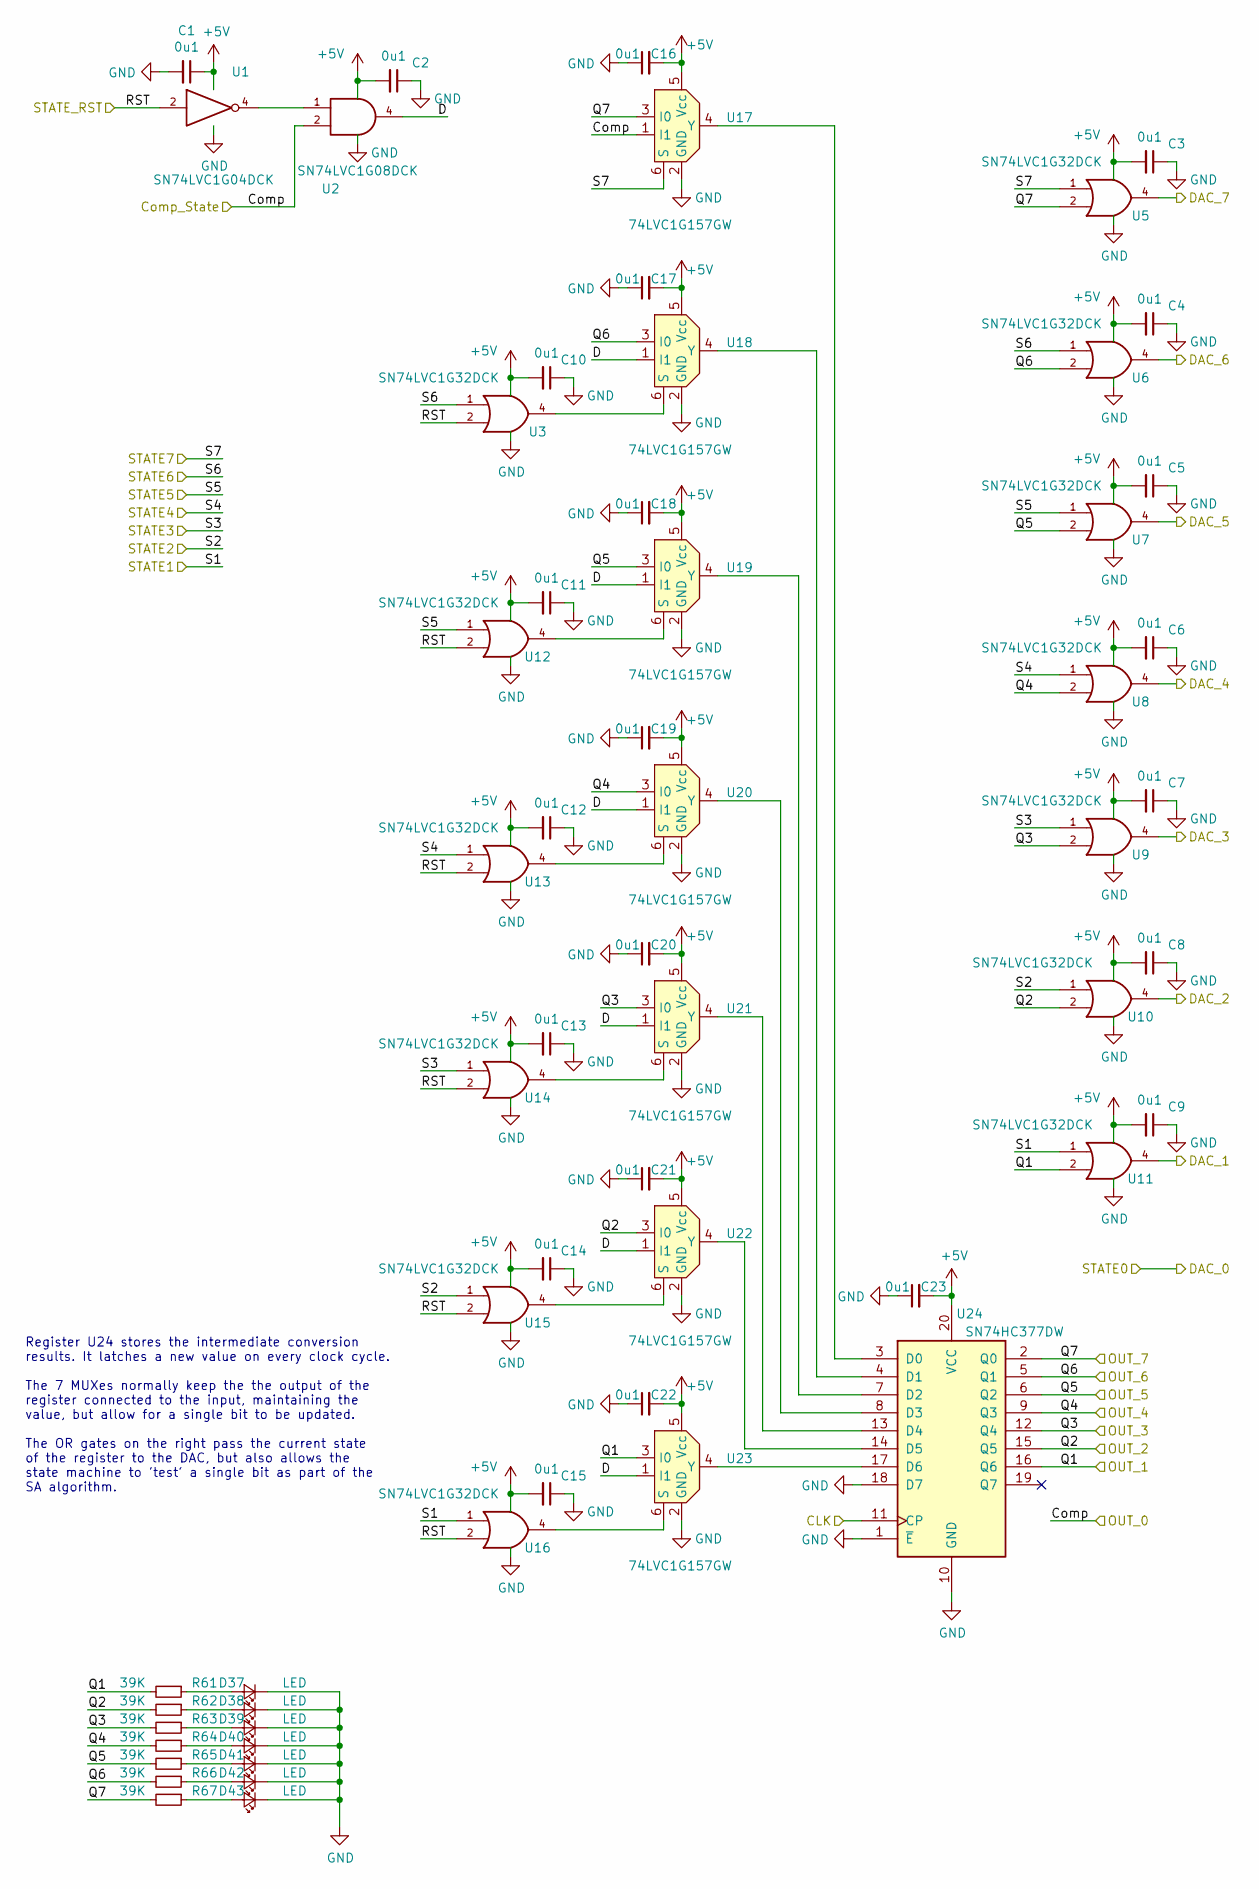
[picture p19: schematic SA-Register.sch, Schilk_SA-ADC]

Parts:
C1, C2, C3, C4, C5, C6, C7, C8, C9, C10, C11, C12, C13, C14, C15, C16, C17, C18, C19, C20, C21, C22, C23: 0u1; C_0603_1608Metric
D37, D38, D39, D40, D41, D42, D43: LED; LED_0603_1608Metric
R61, R62, R63, R64, R65, R66, R67: 39K; R_0603_1608Metric
U1: SN74LVC1G04DCK; SOT-353_SC-70-5
U2: SN74LVC1G08DCK; SOT-353_SC-70-5
U3, U5, U6, U7, U8, U9, U10, U11, U12, U13, U14, U15, U16: SN74LVC1G32DCK; SOT-353_SC-70-5
U17, U18, U19, U20, U21, U22, U23: 74LVC1G157GW; SOT-363_SC-70-6
U24: SN74HC377DW; SOIC-20W_7.5x12.8mm_P1.27mm

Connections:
+5V: C1.1, C2.2, C3.2, C4.2, C5.2, C6.2, C7.2, C8.2, C9.2, C10.2, C11.2, C12.2, C13.2, C14.2, C15.2, C16.2, C17.2, C18.2, C19.2, C20.2, C21.2, C22.2, C23.2, U1.5 (VCC), U2.5 (VCC), U3.5 (VCC), U5.5 (VCC), U6.5 (VCC), U7.5 (VCC), U8.5 (VCC), U9.5 (VCC), U10.5 (VCC), U11.5 (VCC), U12.5 (VCC), U13.5 (VCC), U14.5 (VCC), U15.5 (VCC), U16.5 (VCC), U17.5 (Vcc), U18.5 (Vcc), U19.5 (Vcc), U20.5 (Vcc), U21.5 (Vcc), U22.5 (Vcc), U23.5 (Vcc), U24.20 (VCC); also elsewhere on the board
/Analog/COMP_OUT: U2.2, U17.1 (I1); also elsewhere on the board
/Analog/D1: U11.4; also elsewhere on the board
/Analog/D2: U10.4; also elsewhere on the board
/Analog/D3: U9.4; also elsewhere on the board
/Analog/D4: U8.4; also elsewhere on the board
/Analog/D5: U7.4; also elsewhere on the board
/Analog/D6: U6.4; also elsewhere on the board
/Analog/D7: U5.4; also elsewhere on the board
/Clock/CLK: U24.11 (CP); also elsewhere on the board
/Output/OUT_1: R61.2, U11.2, U23.3 (I0), U24.16 (Q6); also elsewhere on the board
/Output/OUT_2: R62.2, U10.2, U22.3 (I0), U24.15 (Q5); also elsewhere on the board
/Output/OUT_3: R63.2, U9.2, U21.3 (I0), U24.12 (Q4); also elsewhere on the board
/Output/OUT_4: R64.2, U8.2, U20.3 (I0), U24.9 (Q3); also elsewhere on the board
/Output/OUT_5: R65.2, U7.2, U19.3 (I0), U24.6 (Q2); also elsewhere on the board
/Output/OUT_6: R66.2, U6.2, U18.3 (I0), U24.5 (Q1); also elsewhere on the board
/Output/OUT_7: R67.2, U5.2, U17.3 (I0), U24.2 (Q0); also elsewhere on the board
/SA-Register.sch/D: U2.4, U18.1 (I1), U19.1 (I1), U20.1 (I1), U21.1 (I1), U22.1 (I1), U23.1 (I1)
/SA-Register.sch/STATE1: U11.1, U16.1; also elsewhere on the board
/SA-Register.sch/STATE2: U10.1, U15.1; also elsewhere on the board
/SA-Register.sch/STATE3: U9.1, U14.1; also elsewhere on the board
/SA-Register.sch/STATE4: U8.1, U13.1; also elsewhere on the board
/SA-Register.sch/STATE5: U7.1, U12.1; also elsewhere on the board
/SA-Register.sch/STATE6: U3.1, U6.1; also elsewhere on the board
/SA-Register.sch/STATE7: U5.1, U17.6 (S); also elsewhere on the board
/SA-Register.sch/STATE_RST: U1.2, U3.2, U12.2, U13.2, U14.2, U15.2, U16.2; also elsewhere on the board
GND: C1.2, C2.1, C3.1, C4.1, C5.1, C6.1, C7.1, C8.1, C9.1, C10.1, C11.1, C12.1, C13.1, C14.1, C15.1, C16.1, C17.1, C18.1, C19.1, C20.1, C21.1, C22.1, C23.1, D37.1 (K), D38.1 (K), D39.1 (K), D40.1 (K), D41.1 (K), D42.1 (K), D43.1 (K), U1.3 (GND), U2.3 (GND), U3.3 (GND), U5.3 (GND), U6.3 (GND), U7.3 (GND), U8.3 (GND), U9.3 (GND), U10.3 (GND), U11.3 (GND), U12.3 (GND), U13.3 (GND), U14.3 (GND), U15.3 (GND), U16.3 (GND), U17.2 (GND), U18.2 (GND), U19.2 (GND), U20.2 (GND), U21.2 (GND), U22.2 (GND), U23.2 (GND), U24.1 (~E), U24.10 (GND), U24.18 (D7); also elsewhere on the board
unnamed: D37.2 (A), R61.1
unnamed: D38.2 (A), R62.1
unnamed: D39.2 (A), R63.1
unnamed: D40.2 (A), R64.1
unnamed: D41.2 (A), R65.1
unnamed: D42.2 (A), R66.1
unnamed: D43.2 (A), R67.1
unnamed: U1.4, U2.1
unnamed: U12.4, U19.6 (S)
unnamed: U13.4, U20.6 (S)
unnamed: U14.4, U21.6 (S)
unnamed: U15.4, U22.6 (S)
unnamed: U16.4, U23.6 (S)
unnamed: U17.4 (Y), U24.3 (D0)
unnamed: U18.4 (Y), U24.4 (D1)
unnamed: U3.4, U18.6 (S)
unnamed: U19.4 (Y), U24.7 (D2)
unnamed: U20.4 (Y), U24.8 (D3)
unnamed: U21.4 (Y), U24.13 (D4)
unnamed: U22.4 (Y), U24.14 (D5)
unnamed: U23.4 (Y), U24.17 (D6)

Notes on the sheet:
Register U24 stores the intermediate conversion results. It latches a new value on every clock cycle. The 7 MUXes normally keep the the output of the register connected to the input, maintaining the value, but allow for a single bit to be updated. The OR gates on the right pass the current state of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

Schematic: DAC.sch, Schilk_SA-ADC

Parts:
R41, R42, R43, R44, R45, R46, R47, R48, R49: 20K 0.1%; R_0603_1608Metric
R50, R51, R52, R53, R54, R55, R56: 10K 0.1%; R_0603_1608Metric

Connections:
/Analog/DAC/D0: R42.2; also elsewhere on the board
/Analog/DAC/D1: R43.2; also elsewhere on the board
/Analog/DAC/D2: R44.2; also elsewhere on the board
/Analog/DAC/D3: R45.2; also elsewhere on the board
/Analog/DAC/D4: R46.2; also elsewhere on the board
/Analog/DAC/D5: R47.2; also elsewhere on the board
/Analog/DAC/D6: R48.2; also elsewhere on the board
/Analog/DAC/D7: R49.2; also elsewhere on the board
/Analog/DAC/Vdac: R49.1, R56.1; also elsewhere on the board
GND: R41.2; also elsewhere on the board
unnamed: R41.1, R42.1, R50.1
unnamed: R43.1, R50.2, R51.2
unnamed: R44.1, R51.1, R52.2
unnamed: R45.1, R52.1, R53.2
unnamed: R46.1, R53.1, R54.2
unnamed: R47.1, R54.1, R55.2
unnamed: R48.1, R55.1, R56.2

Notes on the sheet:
R2R DAC Use Precision Resistors, Optimally <0.5%

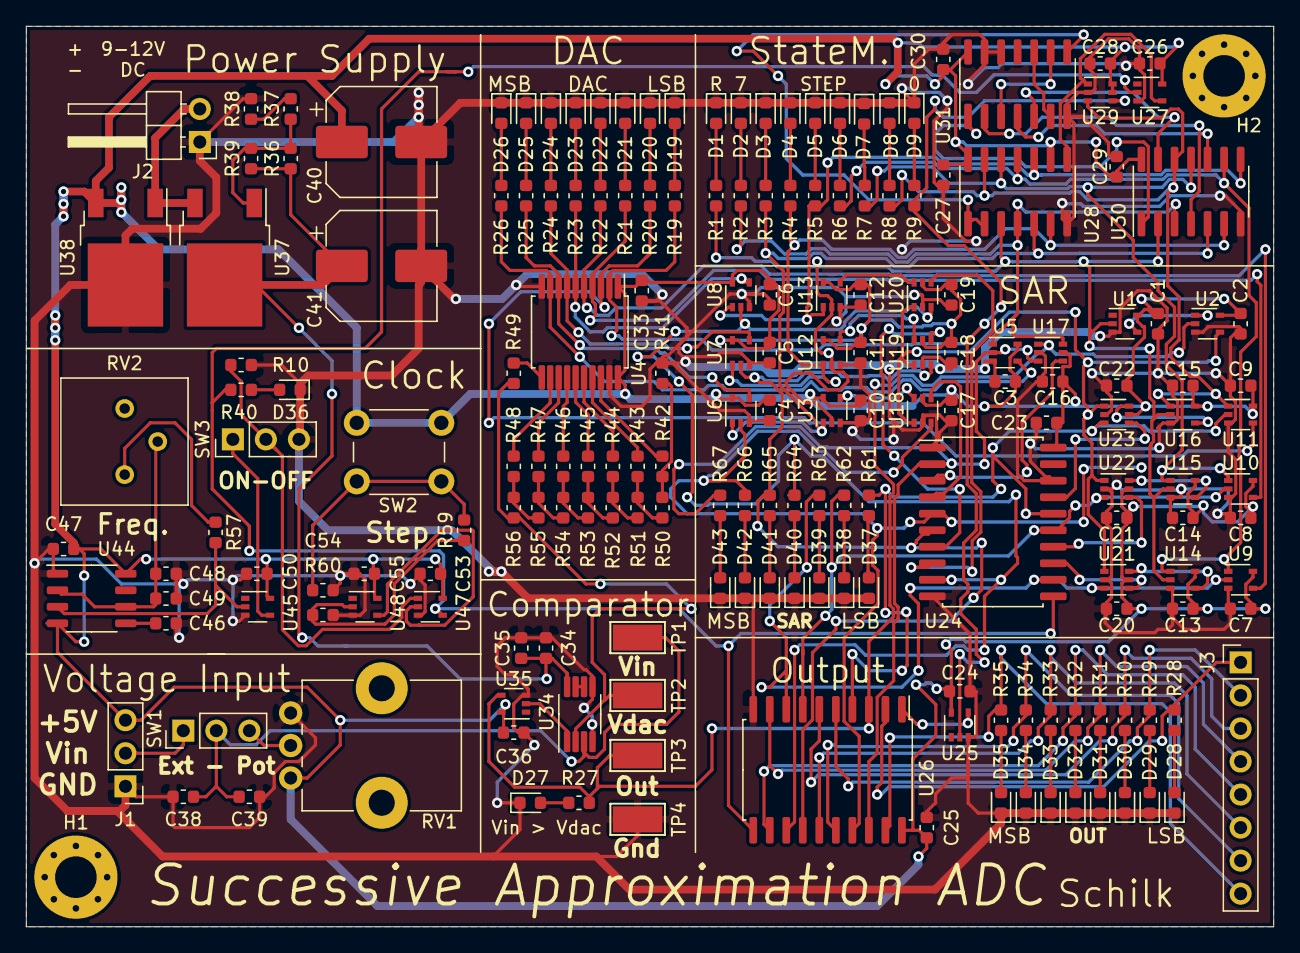
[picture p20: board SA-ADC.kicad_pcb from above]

Board: 2 copper layers, 95.9 x 69.2 mm, 191 parts (0 on the bottom side), 127 nets.

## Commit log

2020-02-13 v0.0 - Initial Commit
    Initial Commit. State of Project for production of v0.0.
    [Analog.sch, Clock.sch, Counter.sch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]
2020-02-13 fixed version numbering in schematic/board project files & pdf
    [Analog.sch, Clock.sch, Counter.sch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]
2020-02-13 Added v0.0 Gerbers
2020-02-14 Added Render of v0.0 PCB
2020-04-09 Removed version nums
    [SA-ADC.kicad_pcb, SA-ADC.sch]
2020-04-09 Fixed netlist-conformity due to renamed schematic sheet.
    [SA-ADC.kicad_pcb]
2020-04-09 Fixed missing grounding on de-bounce cap
    [Clock.sch, SA-ADC.kicad_pcb]
2020-04-09 fixed small typos
    [PWR.sch]
2020-06-02 Greatly simplified Circuit in Simulation
2020-06-02 Schematic Update First Draft, ERC Passed
    [Analog.sch, Clock.sch, DAC.sch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]
2020-06-03 First part placement
    [Analog.sch, Clock.sch, Output.sch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]
2020-06-03 First Layout (All Connected, passes DRC)
    [SA-ADC.kicad_pcb, StateMaschine.sch]
2020-06-08 Added GND test-point
    [Analog.sch, SA-ADC.kicad_pcb]
2020-06-11 Updated Clock Component Values
    [Clock.sch]
2020-06-11 Fixed State Numbering/Wiring Order
    [Analog.sch, PWR.sch, SA-ADC.kicad_pcb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]
2020-06-11 Generated Production Files
    [Output.sch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]
2020-06-11 Updated Documentation
    [SA-Register.sch, StateMaschine.sch]
2020-07-08 PCB v0.2.
    [Analog.sch, Clock.sch, DAC.sch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]
2020-08-26 v0.3 Changed to Schmitt-Trigger ICs Added pull-down resistor to Clock Enable
    [Analog.sch, Clock.sch, DAC.sch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]
2020-08-26 Added PCB picture
2020-08-26 Added PCB picture to README
2026-02-06 Added Example Traces
2026-02-06 Show KiCad in github language stats.
